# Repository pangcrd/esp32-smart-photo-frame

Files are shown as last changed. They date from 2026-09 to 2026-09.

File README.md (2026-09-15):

# Photo Frame Open Source Project











An ESP32-powered smart photo frame that displays images from an SD card and provides a web dashboard for remote management.

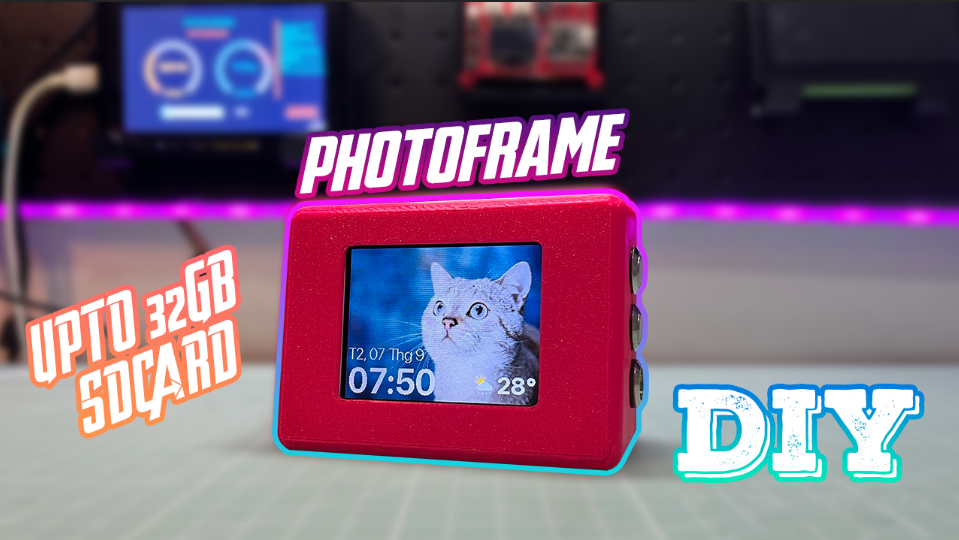
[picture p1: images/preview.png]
demo (https://youtu.be/XxymCvWz6dY)

## Features

- Automatic photo slideshow from an SD card
- Responsive web dashboard for phones, tablets, and computers
- WiFi scanning, setup, reset, and status monitoring
- Image upload, crop, rotate, zoom, and deletion
- JPG/JPEG support with an optimized `320 x 240` display size
- Adjustable slideshow interval from 1 to 3600 seconds
- Weather information by latitude, longitude, timezone, and city
- CPU temperature, free RAM, WiFi signal, uptime, IP address, and SD card status
- English and Vietnamese interface
- Light/dark themes and customizable accent colors
- Device restart and factory reset options

## Project Review

| Front | Left Side |
| --- | --- |
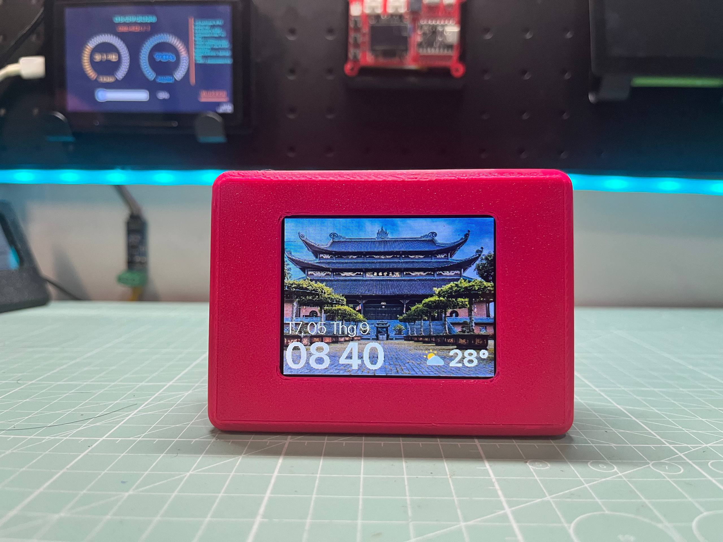
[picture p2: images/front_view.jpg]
Front view
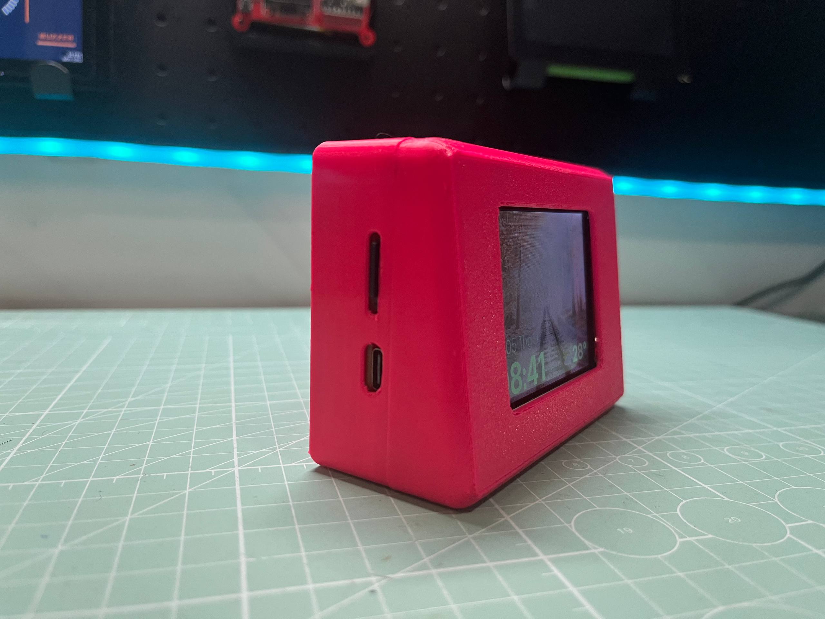
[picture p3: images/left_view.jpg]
Left side view
|  |  |

| Right Side | Back Side |
| --- | --- |
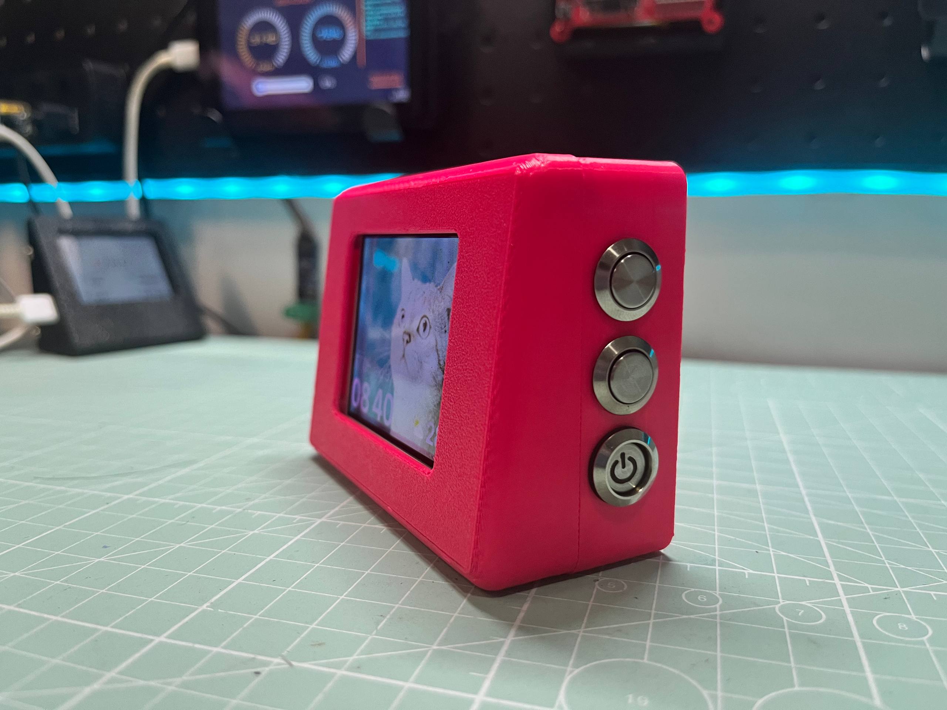
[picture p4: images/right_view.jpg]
Right side view
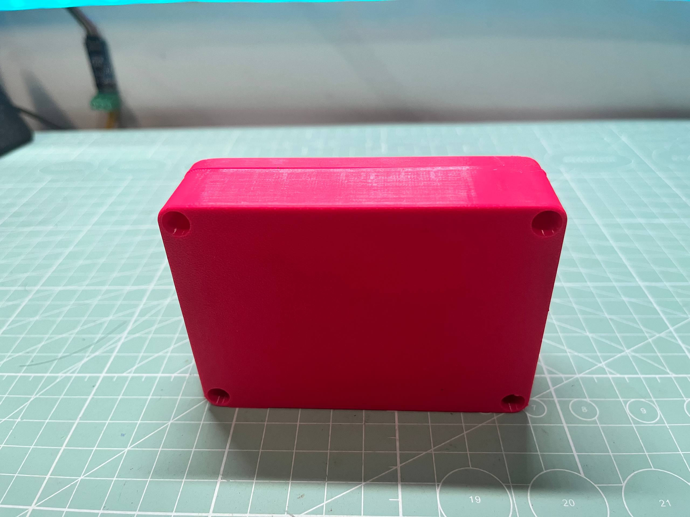
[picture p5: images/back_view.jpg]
Back side view
|  |  |

## Webapp Preview

| Home Page | WiFi Page |
| --- | --- |
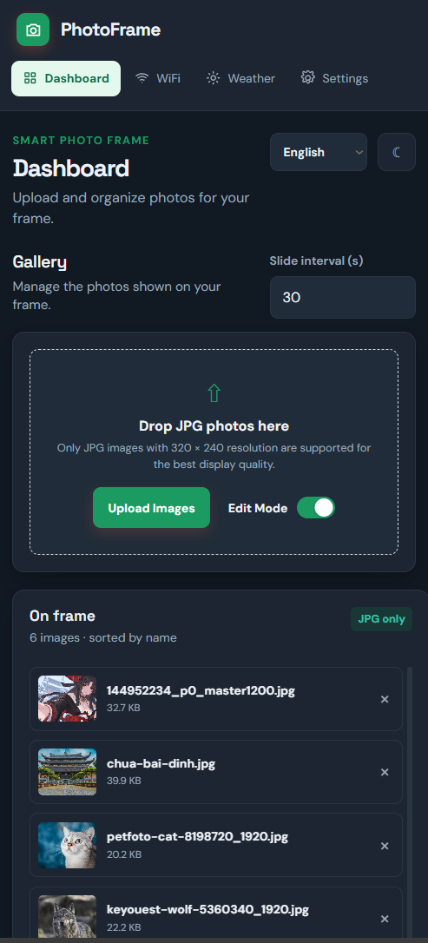
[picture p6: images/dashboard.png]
Home page
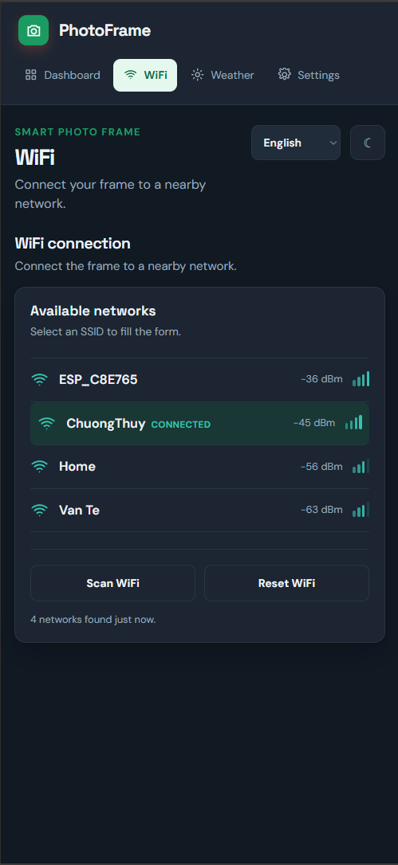
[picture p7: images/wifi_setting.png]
WiFi page
|  |  |

| Weather Page | Settings Page |
| --- | --- |
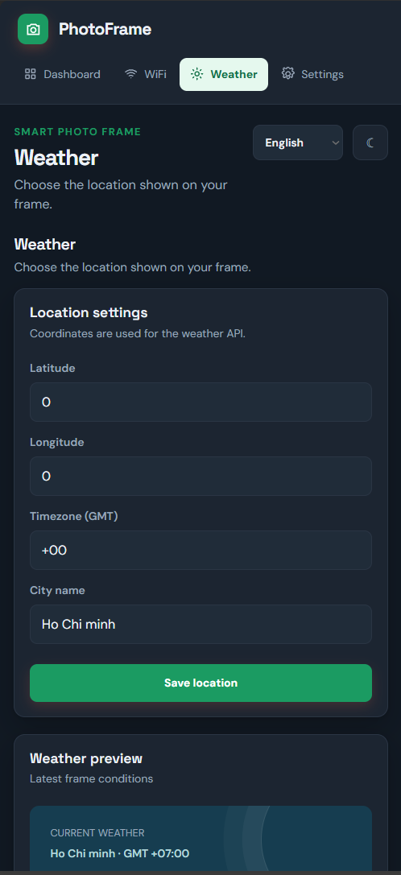
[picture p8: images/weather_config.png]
Weather page
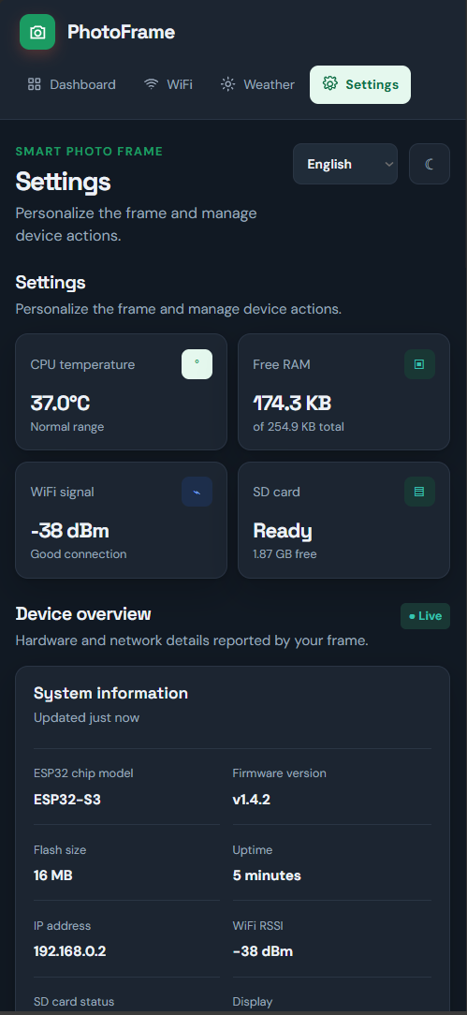
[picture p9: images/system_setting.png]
Settings page
|  |  |

## Quick Start

1. Power on the PhotoFrame.
2. Connect your phone or computer to the same WiFi network.
3. Open the device IP address in a browser, or try `photoframe.local` when mDNS is available.
4. Open **Gallery** to upload photos.
5. Open **Weather** to configure a location.

If WiFi has not been configured, the PhotoFrame starts in **AP mode**:

1. Connect your phone or computer to the WiFi network `PhotoFrame-Setup`.
2. Open `http://192.168.4.1` in a browser.
3. Goto wifi page and configure your home WiFi network.
4. Reconnect your phone or computer to the newly configured WiFi network after the PhotoFrame restarts.

## Photo Requirements

- Formats: `.jpg` and `.jpeg`
- Recommended size: `320 x 240` pixels
- Use **Edit Mode** to crop, reposition, zoom, or rotate images with other dimensions.

Keep at least 20 MB free on the SD card. Do not remove the card during uploads or deletions.

## Weather Setup

In **Weather**, enter:
- Latitude
- Longitude
- GMT timezone, such as `+07` or `-05`
- City name  
**You can get your "Latitude - Longitude" with Google map or Apple map**

An Internet connection is required to update weather data.

## Settings

Use **Settings** to change the theme and accent color, restart the device, or restore factory settings. Factory reset removes WiFi, weather, gallery, and slideshow settings, but does not delete photos stored on the SD card.

## Schematic & PCB Design
**Schematic diagram**   
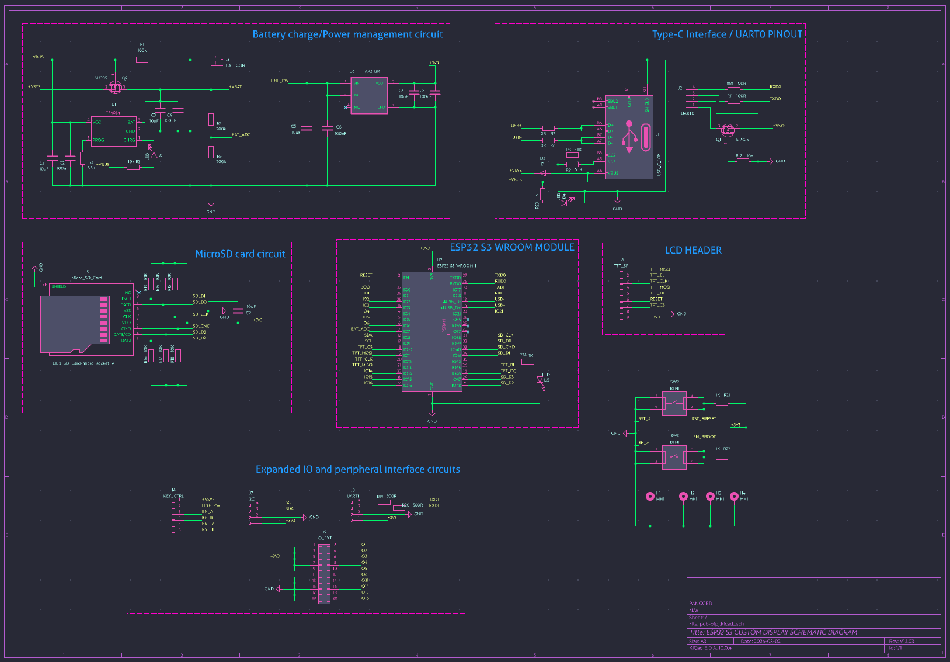
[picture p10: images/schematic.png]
sch
  

**PCB view layout**  
| PCB front view | PCB back view  |
| --- | --- |
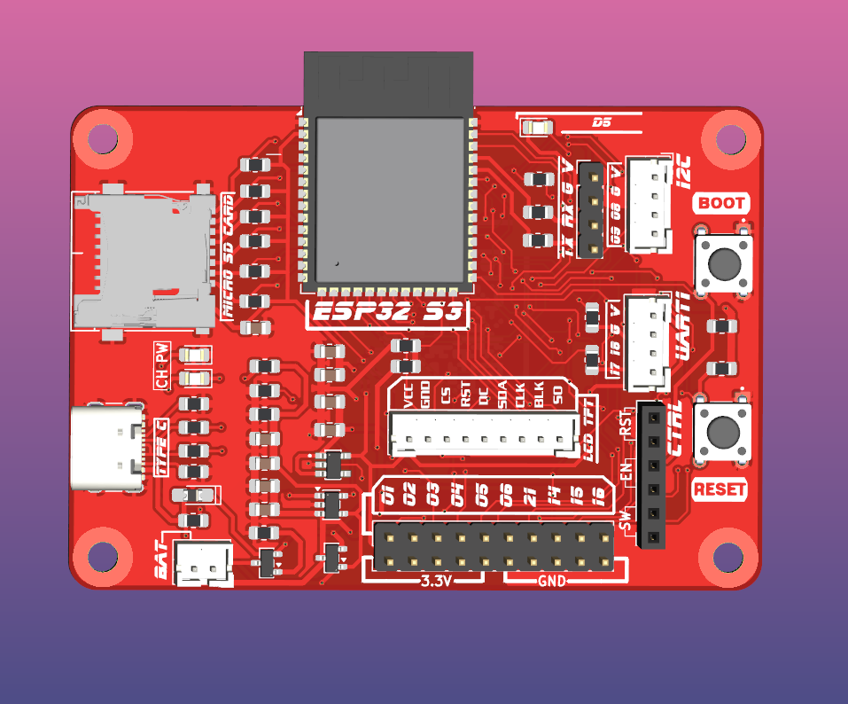
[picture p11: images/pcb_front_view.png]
front view
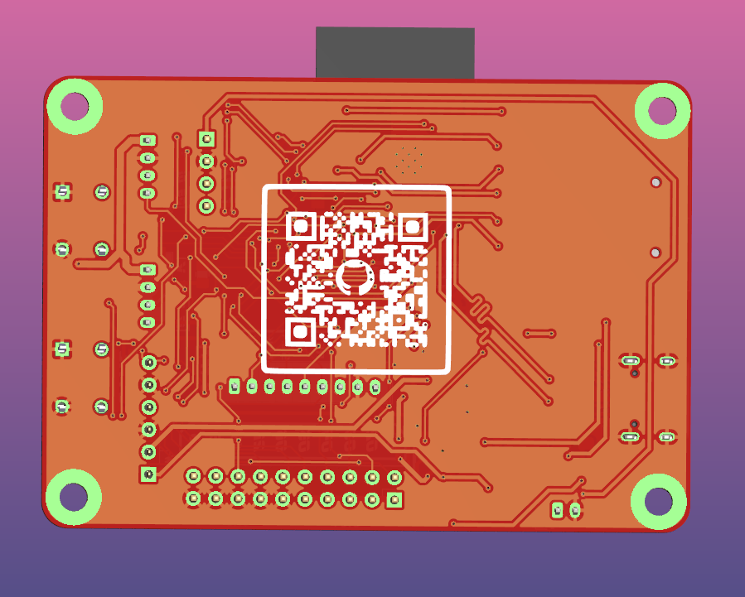
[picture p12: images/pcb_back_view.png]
back view
|  |  |

## JLCPCB Sponsor

If you are looking for high-quality PCB and stencil manufacturing, [JLCPCB](https://jlcpcb.com/coupon-center?from=pangcrd_coupon) is a great option and a familiar name among makers and engineers.

With advanced equipment and a professional manufacturing process, JLCPCB delivers reliable quality while keeping the process simple, from manufacturing to delivery at your doorstep.

JLCPCB also offers a PCB layout service for turning schematics into production-ready PCB files. Their engineers provide free reviews within three hours and follow an efficient workflow to help shorten your time to market.

To get started, visit the [JLCPCB ordering page](https://jlcpcb.com/promotion/1776849103?from=pangcrd_105coupon), upload your schematics and requirements, then choose the settings you need. Check the current layout promotion for a potential `$105` coupon.

## Recommended Parts

| Part | Suggested specification | Affiliate link |
| --- | --- | --- |
| Display | 2.8-inch LCD, 240 x 320 | [AliExpress](https://s.click.aliexpress.com/e/_c2vXjECt)<br>[Shoppe](https://shopee.vn/product/145746151/57217688896/) |
| Microcontroller | My ESP32-S3 custom board | [Shoppe](https://shopee.vn/product/145746151/54867710027/) |
| Enclosure | 3D printer part | [Shoppe](https://shopee.vn/product/145746151/58017697923/) |
| Custom your own | ESP32-S3 N16R8 | [AliExpress](https://s.click.aliexpress.com/e/_c3ljzkZb) |
| Adafruit Micro SDcard| SDIO Card Breakout | [AliExpress](https://s.click.aliexpress.com/e/_c45LSBBF) |
| Heat-set inserts M3 | M3*4*4.2 | [ AliExpress](https://s.click.aliexpress.com/e/_c3gRMkTf) |
| Push button | Momentary 2pcs/latching 1pcs | [AliExpress](https://s.click.aliexpress.com/e/_c3XV5Hi1) |
| Micro SD card | 1 GB or larger | [AliExpress](https://s.click.aliexpress.com/e/_c3R9ssnX) |

## Wiring diagram  

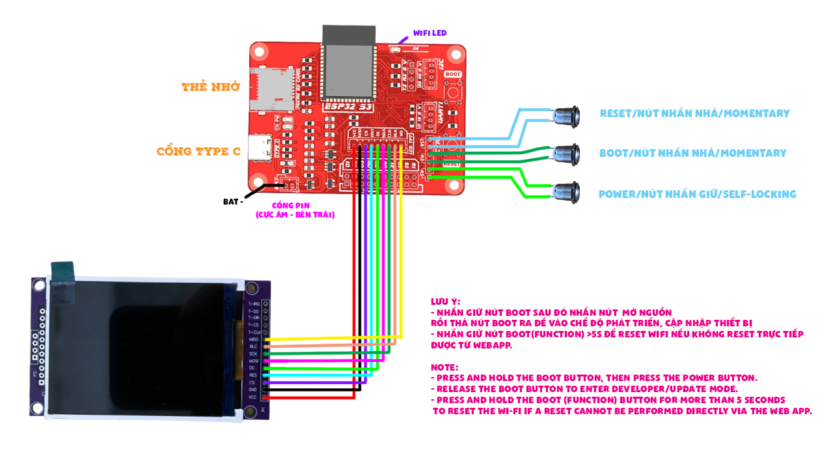
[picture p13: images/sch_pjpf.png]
sch1
  

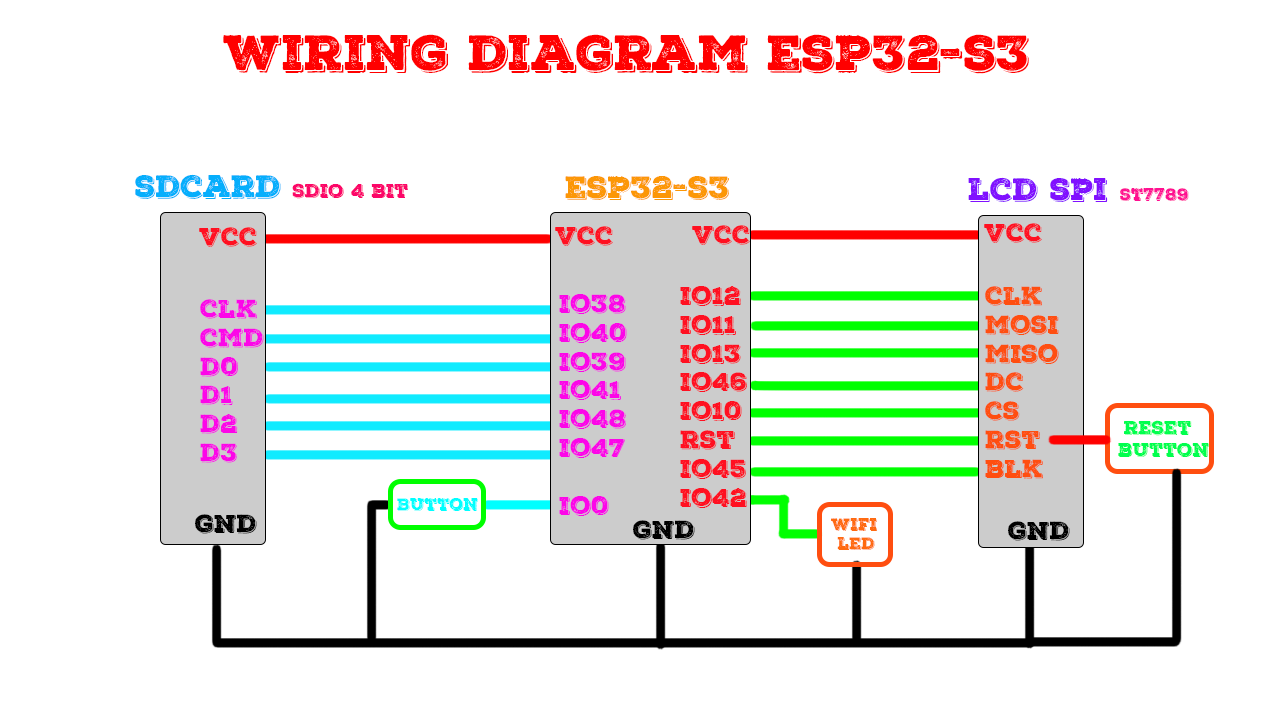
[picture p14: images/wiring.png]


## Firmware upload 
- **This firmware version only use for ST7789 LCD driver...**
- **If you want use another LCD driver, you should build your own firmware with IDE**
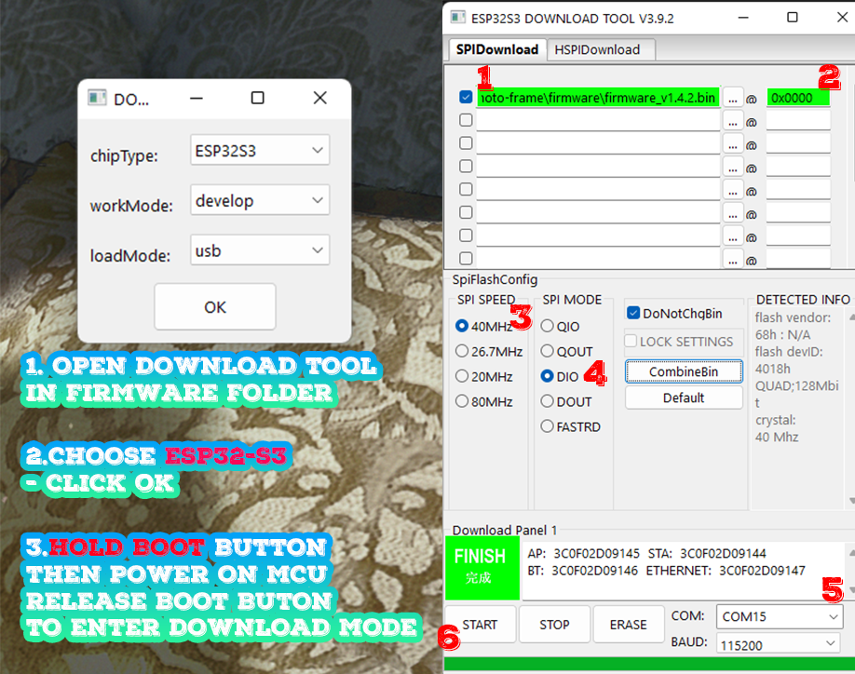
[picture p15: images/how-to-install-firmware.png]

- **Upload firmware with online tool**  
 [Online download firmware page](https://espressif.github.io/esptool-js/)

## Troubleshooting

- **Dashboard unavailable:** Verify power, WiFi connection, device IP, and `photoframe.local` support.
- **Photos missing:** Check the SD card, file extension, and available storage.
- **Upload failed:** Use JPG/JPEG, confirm `320 x 240` dimensions, or enable Edit Mode.
- **Weather not updating:** Check Internet access and location values.
- **Non-commercial end-user**

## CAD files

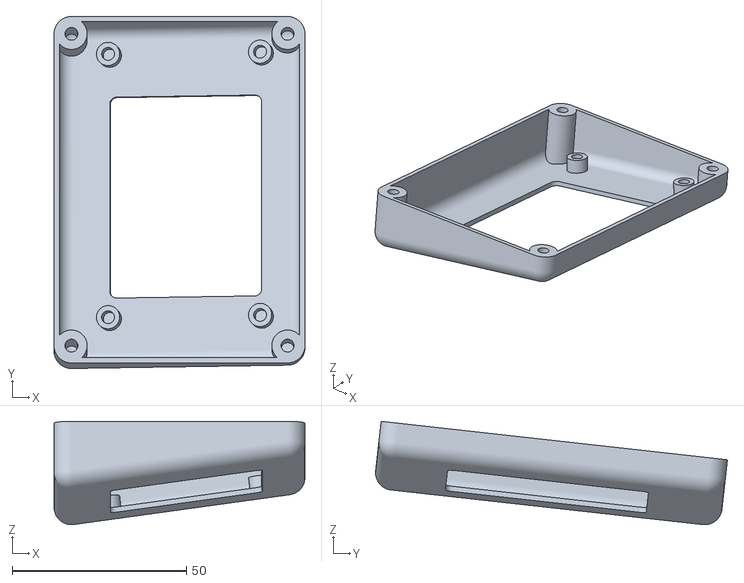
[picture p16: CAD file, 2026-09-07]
3D printer files/lcd_cover-Body.stl
72.0 x 101.0 x 29.7

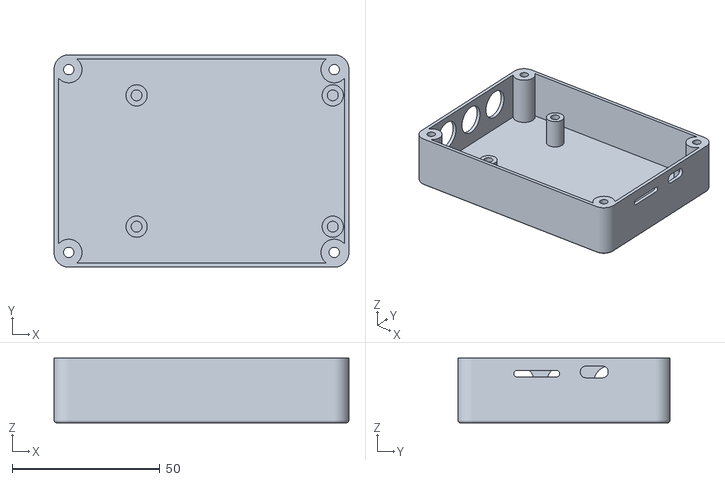
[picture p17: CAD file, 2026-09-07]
3D printer files/bottom-Body.stl
100.0 x 72.0 x 22.0

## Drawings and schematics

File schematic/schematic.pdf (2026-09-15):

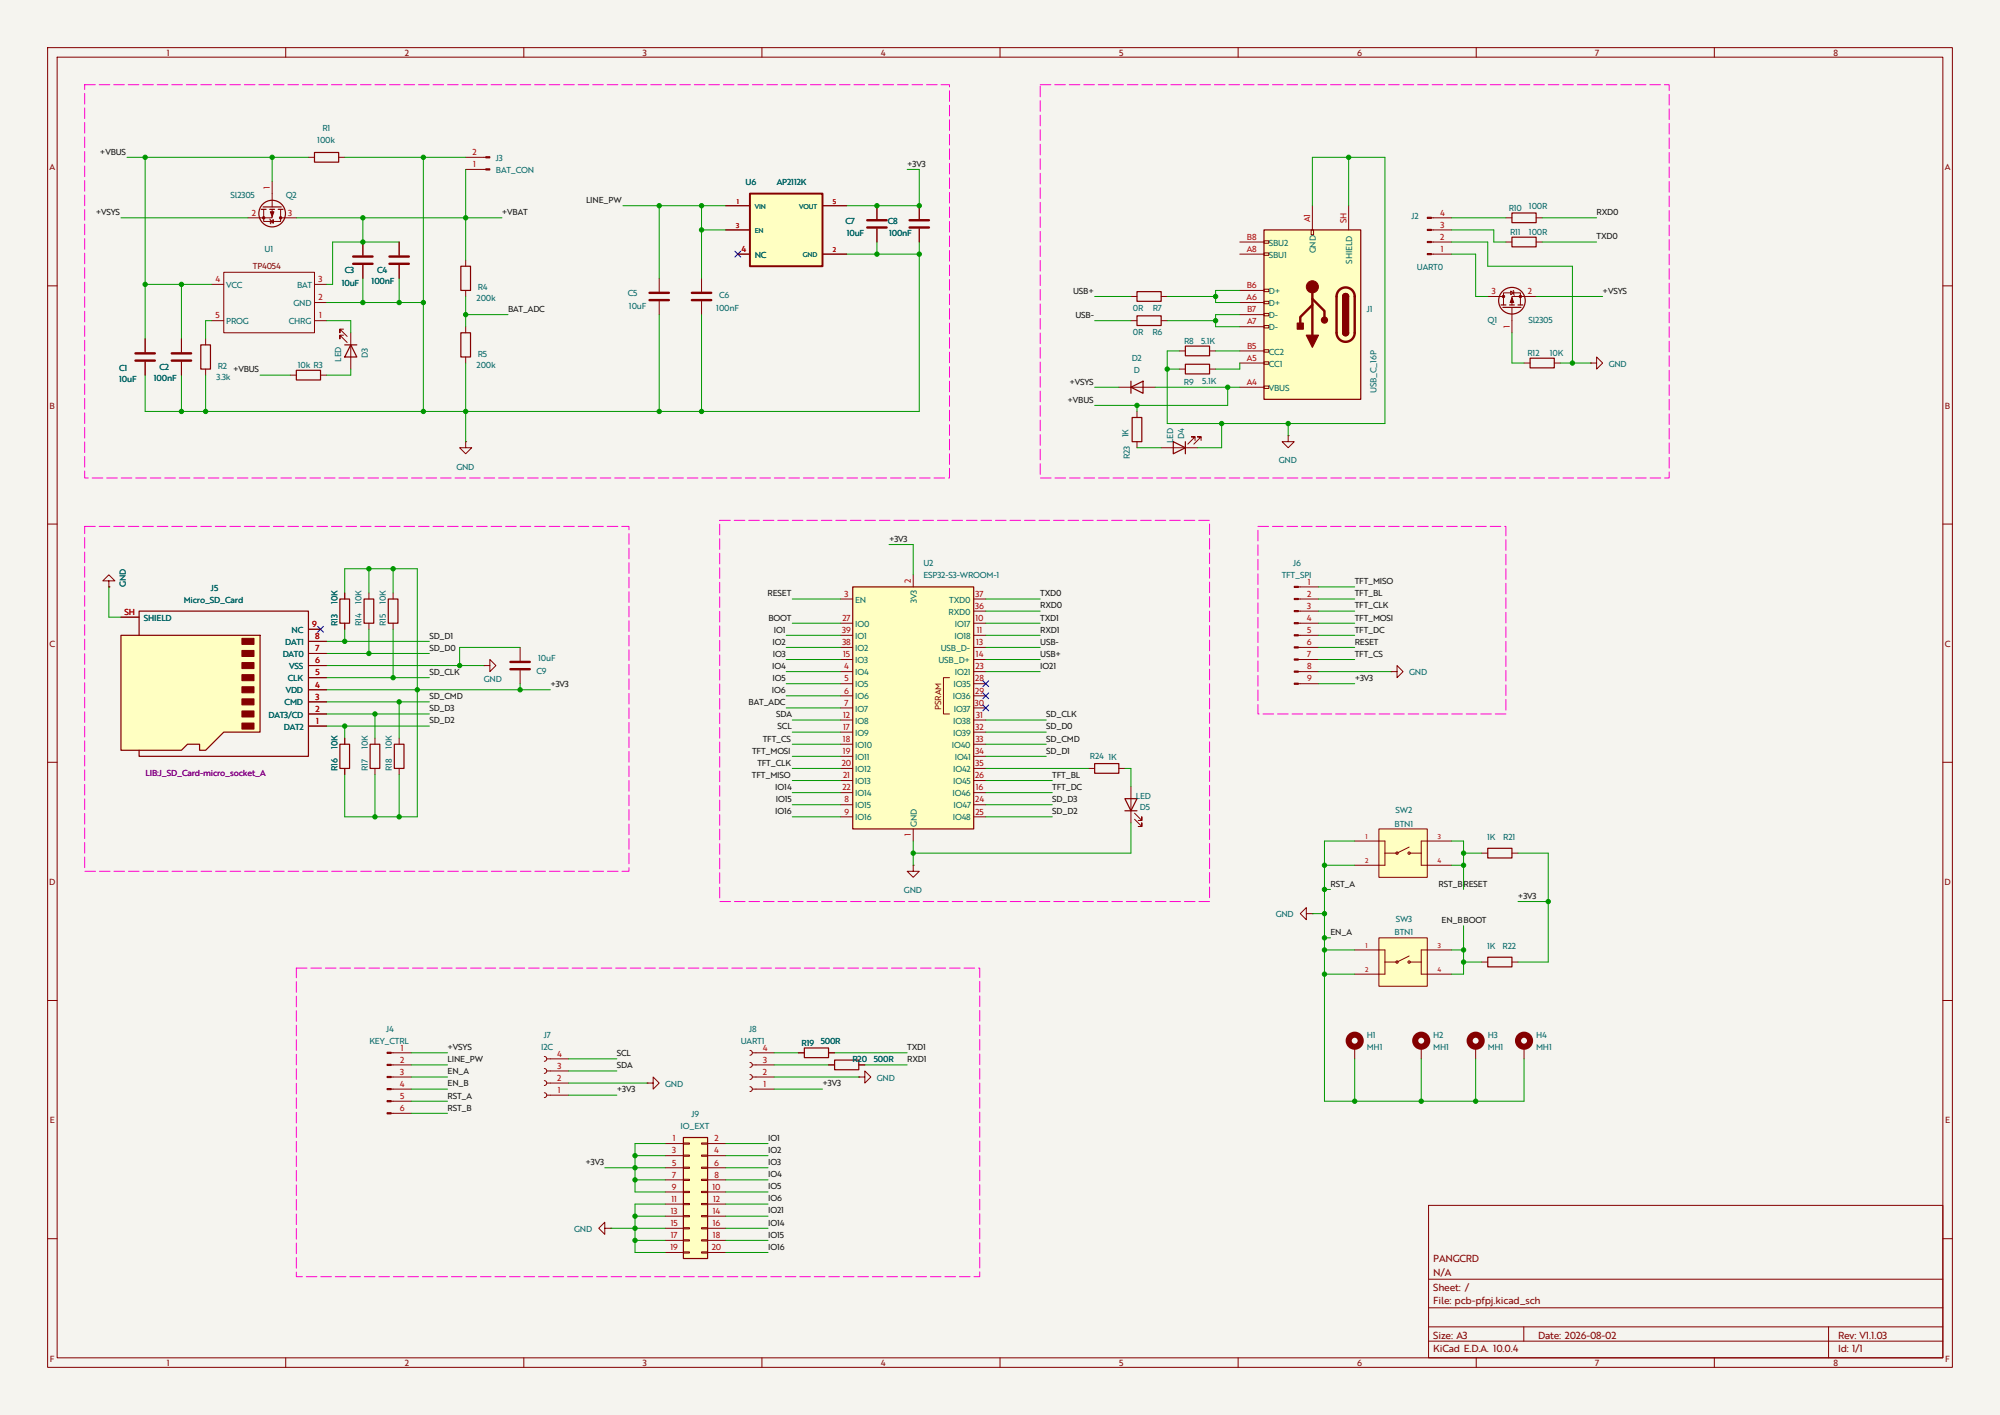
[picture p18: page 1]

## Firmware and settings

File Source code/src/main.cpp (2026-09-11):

///////////////////////////////////////////////////////////////////////////////
//                                                                           //
// PhotoFrame Project                                                        //
// LVGL V9.3                                                                 //
// Youtube:https://www.youtube.com/@pangcrd                                  //
// Github: https://github.com/pangcrd                                        //
//                                                                           //
///////////////////////////////////////////////////////////////////////////////

/*Using LVGL with Arduino requires some extra steps:
 *Be sure to read the docs here: https://docs.lvgl.io/master/integration/framework/arduino.html*/
 
 #include <Arduino.h>
 #include <lvgl.h>
 #include "drv/lvgl_port.h"
 #include "ui/ui.h"
 #include "drv/sd_card_conf.h"
 #include "jpg/jpg_gallery.h"
 #include "sys/system_monitor.h"
 #include "web/web_server_manager.h"
 
void setup()
{
    Serial.begin(115200);
    if (!sd.begin()) {
        Serial.println("SD card init failed!");
    }

    monitor.begin();
    webServerManager.begin();
    
    lvgl_port_init();
    ui_init();
    ui_events_init();
}

void loop()
{
    ui_events_update();
    lvgl_port_loop();

    monitor.update();
    webServerManager.update();

    gallery.setIntervalMs(webServerManager.slideIntervalMs());
    gallery.tick();
}

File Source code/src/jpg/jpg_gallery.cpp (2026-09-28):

#include "jpg_gallery.h"

#include <cstring>
#include "esp_heap_caps.h"


JpgGallery gallery;
LGFX tft;

bool JpgGallery::_bufferOutputCallback(int16_t x, int16_t y, uint16_t w,
                                       uint16_t h, uint16_t *bitmap)
{
    if (!gallery._active || bitmap == nullptr) return false;

    uint16_t *target = gallery._frameBuf[gallery._activeBuf];
    if (target == nullptr || gallery._frameBufPixels == 0) return false;

    const uint16_t screenW = tft.width();
    const uint16_t screenH = tft.height();
    for (uint16_t row = 0; row < h; ++row) {
        const int16_t py = y + row;
        if (py < 0 || py >= screenH) continue;

        for (uint16_t col = 0; col < w; ++col) {
            const int16_t px = x + col;
            if (px < 0 || px >= screenW) continue;
            target[static_cast<size_t>(py) * screenW + px] = bitmap[row * w + col];
        }
    }
    return true;
}

void JpgGallery::cleanupBuffers()
{
    for (int i = 0; i < 2; ++i) {
        if (_imgObj[i] != nullptr) {
            lv_anim_delete(_imgObj[i], nullptr);
        }
    }

    const bool imageAreaValid = _imageArea != nullptr && lv_obj_is_valid(_imageArea);
    if (imageAreaValid) {
        lv_obj_del(_imageArea);
    } else {
        for (int i = 0; i < 2; ++i) {
            if (_imgObj[i] != nullptr && lv_obj_is_valid(_imgObj[i])) {
                lv_obj_del(_imgObj[i]);
            }
        }
    }

    for (int i = 0; i < 2; ++i) {
        _imgObj[i] = nullptr;
        if (_frameBuf[i] != nullptr) {
            heap_caps_free(_frameBuf[i]);
            _frameBuf[i] = nullptr;
        }
        std::memset(&_imgDsc[i], 0, sizeof(_imgDsc[i]));
    }

    _imageArea = nullptr;
    _frameBufPixels = 0;
    _activeBuf = 0;
}

void JpgGallery::stop()
{
    _active = false;
    TJpgDec.setCallback(nullptr);
    cleanupBuffers();
    _firstImageRendered = false;

    _parent = nullptr;
    _files.clear();
    _index = 0;
    _lastShownPath = "";
}

void JpgGallery::start(lv_obj_t *parent, const char *dir,
                       uint8_t rotationPortrait, uint8_t rotationLandscape)
{
    stop();

    if (parent == nullptr || !lv_obj_is_valid(parent)) {
        Serial.println("[Gallery] Parent LVGL khong hop le.");
        return;
    }

    _parent = parent;
    _dir = dir != nullptr ? dir : "/";
    _rotationPortrait = rotationPortrait;
    _rotationLandscape = rotationLandscape;
    tft.setSwapBytes(true);

    _frameBufPixels = static_cast<size_t>(tft.width()) * tft.height();
    if (_frameBufPixels == 0) {
        Serial.println("[Gallery] Kich thuoc framebuffer khong hop le.");
        stop();
        return;
    }

    for (int i = 0; i < 2; ++i) {
        _frameBuf[i] = static_cast<uint16_t *>(
            heap_caps_malloc(_frameBufPixels * sizeof(uint16_t), MALLOC_CAP_SPIRAM));
        if (_frameBuf[i] == nullptr) {
            Serial.printf("[Gallery] Khong cap phat duoc PSRAM buffer #%d\n", i);
            stop();
            return;
        }
        std::memset(_frameBuf[i], 0, _frameBufPixels * sizeof(uint16_t));
    }

    _imageArea = lv_obj_create(_parent);
    if (_imageArea == nullptr) {
        Serial.println("[Gallery] Khong tao duoc image area.");
        stop();
        return;
    }
    lv_obj_remove_style_all(_imageArea);
    lv_obj_set_size(_imageArea, LV_PCT(100), LV_PCT(100));
    lv_obj_set_pos(_imageArea, 0, 0);
    lv_obj_clear_flag(_imageArea, LV_OBJ_FLAG_CLICKABLE);
    lv_obj_clear_flag(_imageArea, LV_OBJ_FLAG_SCROLLABLE);      
    lv_obj_move_background(_imageArea);

    for (int i = 0; i < 2; ++i) {
        _imgDsc[i].header.cf = LV_COLOR_FORMAT_RGB565;
        _imgDsc[i].header.w = tft.width();
        _imgDsc[i].header.h = tft.height();
        _imgDsc[i].data_size = _frameBufPixels * sizeof(uint16_t);
        _imgDsc[i].data = reinterpret_cast<const uint8_t *>(_frameBuf[i]);

        _imgObj[i] = lv_image_create(_imageArea);
        if (_imgObj[i] == nullptr) {
            Serial.printf("[Gallery] Khong tao duoc LVGL image #%d\n", i);
            stop();
            return;
        }
        lv_image_set_src(_imgObj[i], &_imgDsc[i]);
        lv_obj_set_pos(_imgObj[i], 0, 0);
        lv_obj_set_style_opa(_imgObj[i], i == 0 ? LV_OPA_COVER : LV_OPA_TRANSP,
                             LV_PART_MAIN);
    }

    TJpgDec.setCallback(_bufferOutputCallback);
    TJpgDec.setJpgScale(1);
    _active = true;
    refreshFileList();
    _pendingFirstImage = true;
    _lastSwitchMs = millis(); 
}

void JpgGallery::begin(const char *dir, uint8_t rotationPortrait,
                       uint8_t rotationLandscape)
{
    (void)dir;
    (void)rotationPortrait;
    (void)rotationLandscape;
    stop();
    Serial.println("[Gallery] begin() da bi vo hieu; dung start(parent, ...) khi vao gallery.");
}

void JpgGallery::refreshFileList()
{
    const uint32_t startedAt = millis();
    if (!sd.isReady()) {
        Serial.println("[Gallery] SD chua init, khong the refresh.");
        return;
    }

    const String currentPath = _lastShownPath;
    const char *dir = _dir.length() > 0 ? _dir.c_str() : "/";

    _files.clear();
    const auto allFiles = sd.listFiles(dir, nullptr);
    _files.reserve(allFiles.size());
    for (const String &path : allFiles) {
        String lower = path; lower.toLowerCase();
        if (lower.endsWith(".jpg") || lower.endsWith(".jpeg")) _files.push_back(path);
    }

    Serial.printf("[Gallery] Refresh: tim thay %u anh JPEG trong %s elapsed=%lums free=%u min=%u largest=%u\n",
                  static_cast<unsigned>(_files.size()), dir, static_cast<unsigned long>(millis() - startedAt), static_cast<unsigned>(ESP.getFreeHeap()), static_cast<unsigned>(esp_get_minimum_free_heap_size()), static_cast<unsigned>(heap_caps_get_largest_free_block(MALLOC_CAP_8BIT)));

    if (_files.empty()) {
        _index = 0;
        _lastShownPath = "";
        return;
    }

    int foundIndex = -1;
    for (size_t i = 0; i < _files.size(); ++i) {
        if (_files[i] == currentPath) {
            foundIndex = static_cast<int>(i);
            break;
        }
    }

    if (foundIndex >= 0) {
        _index = (static_cast<size_t>(foundIndex) + 1) % _files.size();
    } else {
        _index = 0;
        _lastShownPath = "";
    }
}

void JpgGallery::addFile(const String &path)
{
    if (!_active || path.isEmpty()) return;

    String lower = path;
    lower.toLowerCase();
    if (!lower.endsWith(".jpg") && !lower.endsWith(".jpeg")) return;

    for (const String &file : _files) {
        if (file == path) return;
    }
    _files.push_back(path);
}
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

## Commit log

2026-09-07 Add 3D printer files
    [bottom-Body.stl, lcd_cover-Body.stl]
2026-09-11 Add source code
    [custom_partition.csv]
2026-09-15 Add schematic diagram
2026-09-15 Fix web editor button layout
2026-09-20 Update auto switch screen, button change state
2026-09-20 Fix button transition,incremental cache
    [jpg_gallery.cpp, ui_events.cpp]
2026-09-28 Fix add/remove image without reset device and rescan folder path
    [jpg_gallery.cpp, jpg_gallery.h, web_server_manager.cpp]
